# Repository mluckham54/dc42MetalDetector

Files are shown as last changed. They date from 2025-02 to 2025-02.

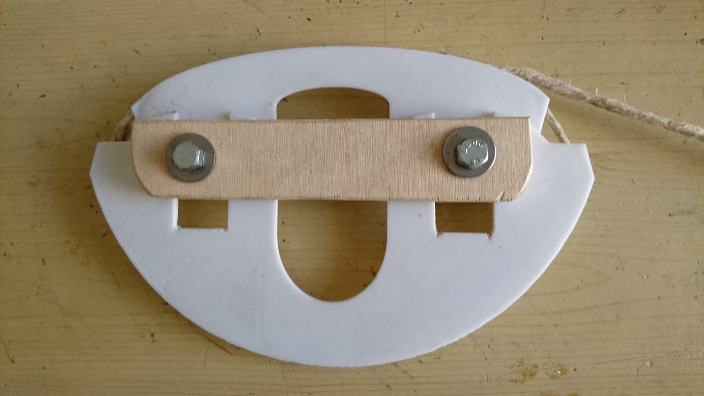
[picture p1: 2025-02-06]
MetalDetector/PrintableParts/DD Coil modifiable - 5966085 - 105percent/images/664fb390-7184-4ca7-937c-c71cdf0065e6.jpeg

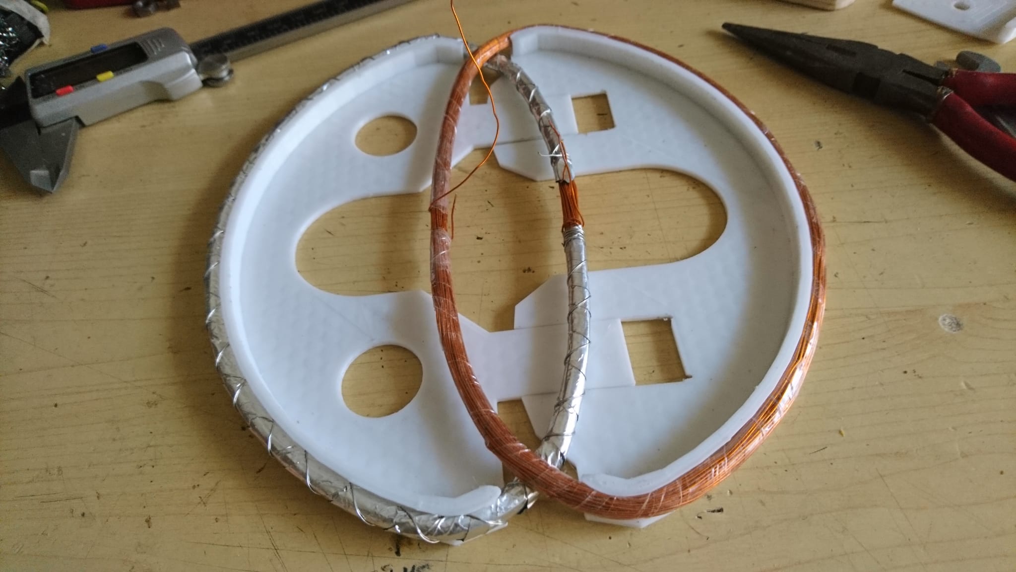
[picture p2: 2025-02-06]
MetalDetector/PrintableParts/DD Coil modifiable - 5966085 - 105percent/images/e20aad1c-73c8-4a4e-adeb-e24c117a30eb.jpeg

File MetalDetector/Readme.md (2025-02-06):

**Induction balance metal detector**

This project is an Induction Balance Metal Detector built around Arduino Uno and a 2-line LCD display module driven by I2C.  A piezo buzzer is used to drive an earphone for audio feedback.

The search coil comprises two D-shaped coils fastened on opposite side of a 230mm diameter plastic plate.  The coils are overlapped in the middle to null or minimize the amount of voltage and current induced into the receiver coil when no metal is present.  Position of the overlap is extremely critical, to tune the lowest voltage to an absolute minimum - at which point the Calibration routine can be run.

The form on which the coils are mounted was 3D printed from "DD Coil modifiable by Gabryxx on Thingiverse: https://www.thingiverse.com/thing:5966085".  The original coil was enlarged to 105% to fit the approx 16-cm coils which had already been wound.  In the end, the coil overlap is about 2.5 cm wide and 18 cm long.

The schematic for the detector was taken from Mirko Pavleski's project https://www.hackster.io/mircemk/diy-sensitive-arduino-ib-metal-detector-with-discrimination-b55e9d, modified to replace the LCD display with one I had on hand.  The dc24 project contains KiCad schematics, Mirko's project did not (only a JPG of the circuit).   The circuit was built up on a perfboard and does not seem to suffer from interference, however take care to use grounded shielded wire pairs running from the perfboard to the coils. Leave the shield grounds at the coil end unconnected.

After learning from the comments in Mirko's YouTube video https://www.youtube.com/watch?v=nkSPy0BPTFc&t=5s "DIY sensitive Arduino Induction Balance Metal Detector with Discrimination (15cm to 50 + cm)" came from David Crocker's github project https://github.com/dc42/arduino, it was decided to use his code rather than Mirko's.

The tuning capacitors across the coils should be adjusted such that the LC networks resonate exactly at the frequency generated by the Timer0 PWM output. An oscilloscope is critical to help understand the circuit and the code behaviour, and to tune the coil resonances and phase detection.  The tuning capacitors should be metallised foil types because stable, accurate values are needed. The other capacitors can be ceramic.

The code contains a lot of notes about the discovery process, tuning the coils, understanding how the code works, fixing some issues in the code, and extending it to my liking.

TODO:  wrap the coils in grounded aluminium foil (with a gap at one point so that it doesn't behave like a shorted turn) so that capacitance between the coils and the ground doesn't cause the system to go out of balance.

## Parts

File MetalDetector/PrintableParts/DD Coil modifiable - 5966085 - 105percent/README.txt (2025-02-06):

DD Coil modifiable by Gabryxx on Thingiverse: https://www.thingiverse.com/thing:5966085

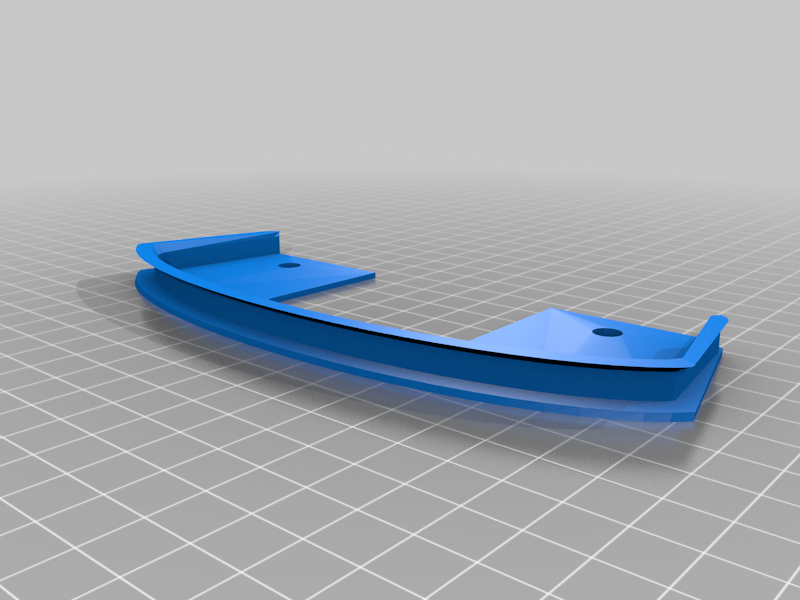
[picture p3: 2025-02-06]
MetalDetector/PrintableParts/DD Coil modifiable - 5966085 - 105percent/images/68960cd5-e284-4ff6-a99d-108c46c3dbc9.png

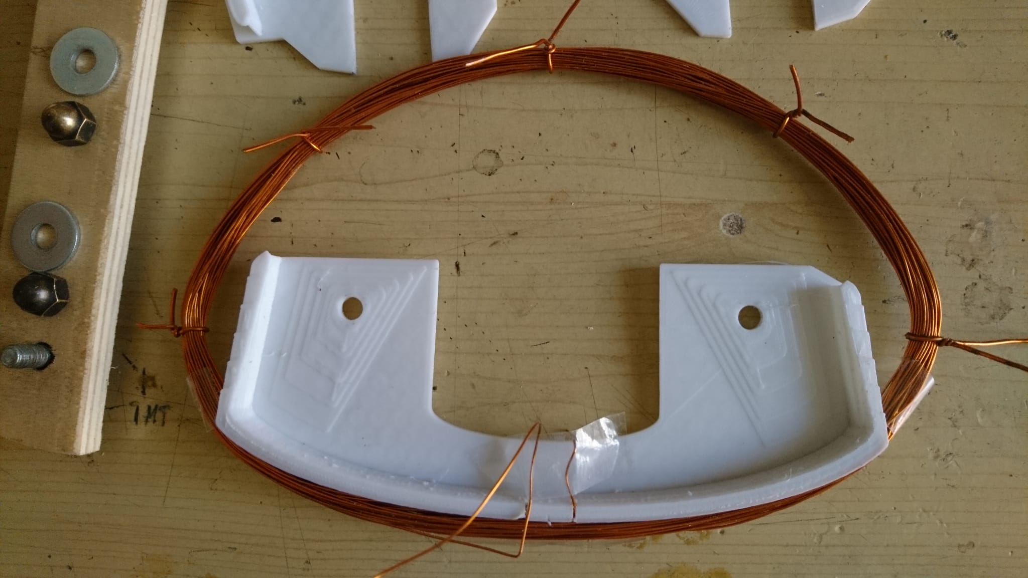
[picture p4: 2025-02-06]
MetalDetector/PrintableParts/DD Coil modifiable - 5966085 - 105percent/images/a11f1c0a-a7c3-48c4-930f-4ecd38f82f80.jpeg

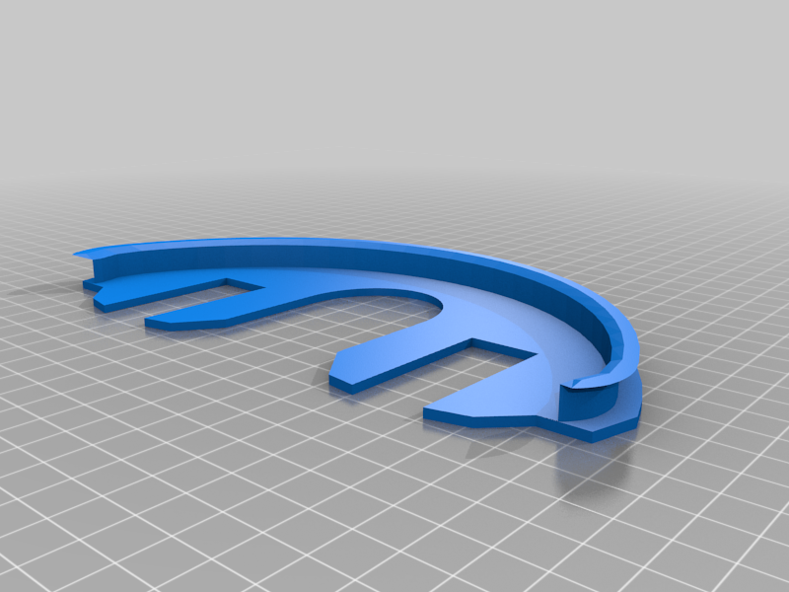
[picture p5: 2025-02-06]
MetalDetector/PrintableParts/DD Coil modifiable - 5966085 - 105percent/images/57a2fe57-1afa-487f-abc0-737dc57a6d6f.png

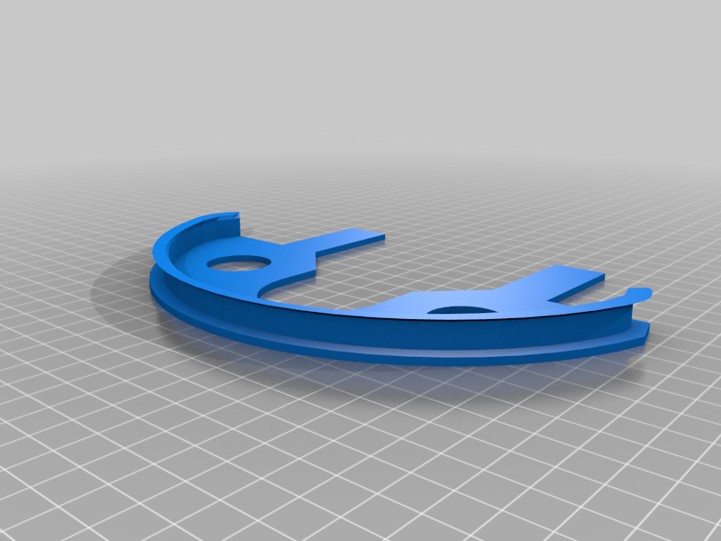
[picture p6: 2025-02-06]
MetalDetector/PrintableParts/DD Coil modifiable - 5966085 - 105percent/images/dc1d90d6-1bc5-4217-a439-5ab050d07a05.png

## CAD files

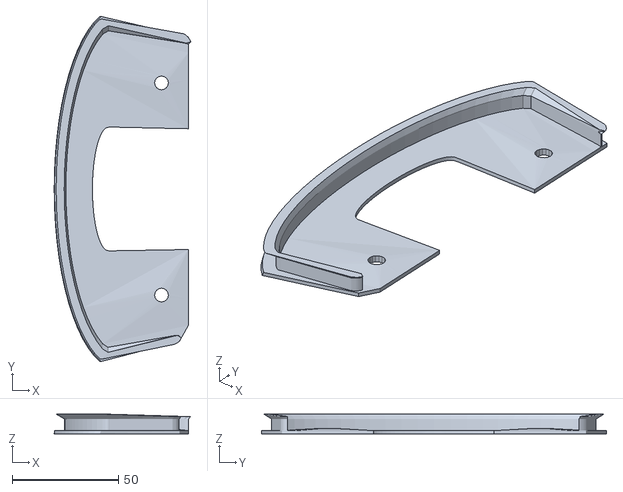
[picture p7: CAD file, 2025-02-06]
MetalDetector/PrintableParts/DD Coil modifiable - 5966085 - 105percent/files/C.stl
64.4 x 162.6 x 9.30

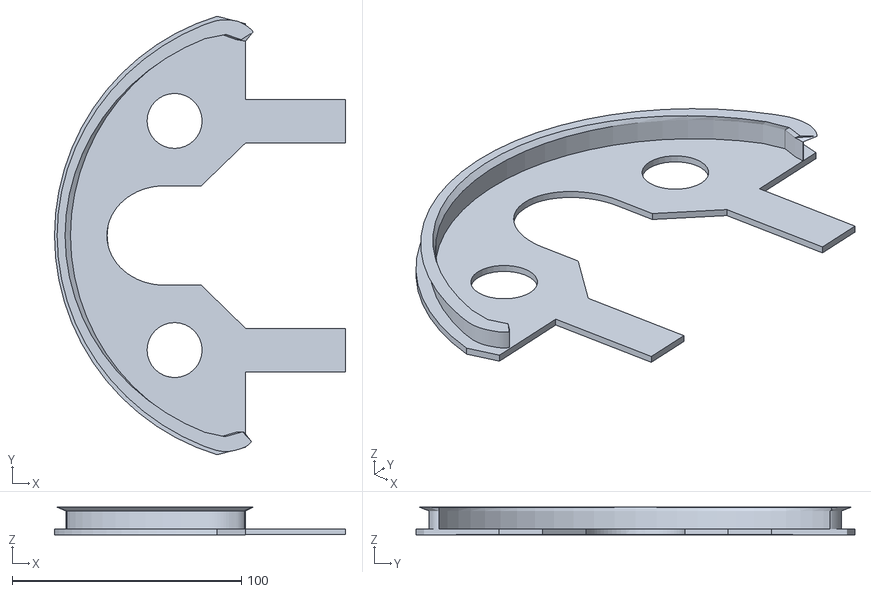
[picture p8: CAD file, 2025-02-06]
MetalDetector/PrintableParts/DD Coil modifiable - 5966085 - 105percent/files/A.stl
127.0 x 191.4 x 12.0

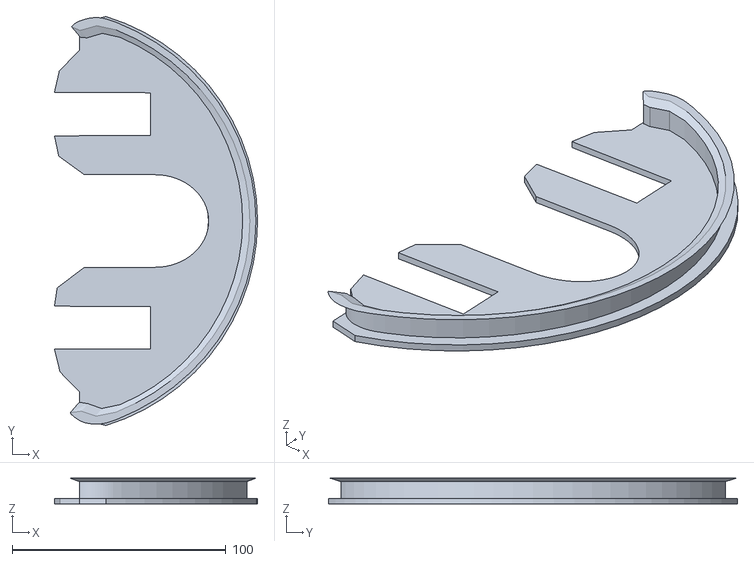
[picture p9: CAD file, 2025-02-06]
MetalDetector/PrintableParts/DD Coil modifiable - 5966085 - 105percent/files/B.stl
95.1 x 191.4 x 12.0

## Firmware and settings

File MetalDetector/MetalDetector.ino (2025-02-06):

// Induction balance metal detector (Mirko Pavleski)
// https://www.hackster.io/mircemk/diy-sensitive-arduino-ib-metal-detector-with-discrimination-b55e9d
// https://www.youtube.com/watch?v=BolEUTYOES0

// from original code by dc42 David Crocker (2013)
// https://github.com/dc42/arduino/blob/master/MetalDetector
//   (his version has support for battery power measurement and adjustable threshold)

// This is a VLF (very low frequency) Induction Balance detector technology and contains two identical coils : transmitter and receiver coil in
// a double-D arrangement.  As with all induction balance detectors, coil balance is very critical. The potentiometer is used to zero the small
// 90 degrees out-of-phase component of the signal (the in-phase component is nulled by adjusting the relative placement (overlap) of the coils
// in typical IB-detector style).
//
// Does the 90 degree out-of-phase component arise from the current in the coil lagging the voltage?  The current in the capacitor leads the voltage
// and is also 90 degrees out-of-phase.  https://eepower.com/technical-articles/understanding-resonance-in-parallel-rlc-circuits/#



// ********************************************************************************************************************
    
#define ENABLE_SOUND       (1)

// control what is printed to the COM port

#define PRINT_TICKS (0)
#define PRINT_ISR_VARS (0)
#define PRINT_ADC_MINMAX (0)
#define PRINT_VOLTS (1)
#define PRINT_FFT (0)
#define PRINT_AMPLITUDE (1)
#define PRINT_PHASE (1)
#define PRINT_AVERAGES (0)
#define PRINT_READINGS (0)
#define PRINT_MATERIAL (0)
#define PRINT_BARS (0)

// control what is dislayed on the LCD

#define DISPLAY_VOLTS (1)
#define DISPLAY_AMPLITUDE (1)
#define DISPLAY_PHASE (1)
#define DISPLAY_MATERIAL (0)



// TRANSMIT & RECEIVE COILS
//
// Two coils of same size and number of winding are required.  A variety of sizes could be considered, probably the larger and more windings the
// better, to have a stronger field pulse for the transmit and more sensitivity for the receive coil.  The voltage and maximum current that can be
// delivered to the coils must be considered also.
//
// The inductance and resonant frequency of a coil, and the parallel-resonance circuit formed by coil and capacitor, can be estimated.  Note that the
// current circulating between coil and capacitor is many times greater than the supply current.
//
// For the coil only: https://www.teslascientific.com/products/coil-resonant-frequency-calculator/
//     wire 0.45mm^2, 15cm dia, 0.5cm height, 44 turns - 1570 kHz, 630.500 µH, 14.400 pF
//     wire 0.45mm^2, 15.5 dia, 0.5cm height, 55 turns - 1333.757 kHz, 956.938 µH, 14.880 pF   (* BUILT)
//     wire 0.45mm^2, 16cm dia, 0.5cm height, 55 turns - 1290 kHz, 989.876 µH, 15.360 pF
//       10⁶ ÷ ((2 × 3.142 ) × √(989.876 µH × 15.360 pF))
//       ≈ 10⁶ ÷ (6.283 × √15204.495) ≈ 10⁶ ÷ (6.283 × 123.307)
//       Resonant Frequency ≈ 1000000 ÷ 774.758 = 1290.726 kilocycles/sec
//       Conductor Length = 3.141 × 0.160 Metres × 55 Turns = 27.646 Metres
//
// For the coil-capacitor L-C circuit: https://www.redcrab-software.com/en/Calculator/Electrics/RCL-Parallel-Resonance-Circuit
//     15.5 cm coil Inductor L  956.938 µH Capacitor C 470 nF Resistor R 1000 Ω Voltage U 5.5 V Decimal places 2   
//                  Resonance Frequency f0 7.5 kHz Total current I0 5.5 mA Currents IL, IC 121.89 mA
//                  Impedance XL/XC 45.12 Ω Q factor 22.16 Damping d 0.05 Bandwidth b 338.63 Hz Upper cut-off fH 7.67 kHz Lower cut-off fL 7.34 kHz
//
// A plastic plate was 3D printed from https://www.thingiverse.com/thing:5966085 (DD Coil Modifiable), enlarged to 105%.  The plate is in two parts,
// one for transmit and the other for receive coil.  The plates can slide together to form an overlap of the D-coils and fixed in place.  When
// installed on the plates, each coil (now D-shaped) is about 20.5 x 13 cm.
//
// Each of the coils was wound on 15.5 cm round form using 55 turns of 0.45mm^2 enameled copper wire.  The estimated diameter across the coil 0.5 cm.
// Wrap insulating tape around each coil to bundle the wires together, and form each into a D shape.  Add insulated leads from the coil (head) to run
// back to the electronics enclosure.
//
// The coils as-built were measured using a cheap ESD L/C meter.  The coil w/BL+WH wires was 987.8 uH, w/BLU+YEL wires 1029 uH - agreeing pretty closely
// to the calculated value of 956 uH.  Measurement was done after the coils were wrapped in tape, making it impossible to adjust the coil's inductance by
// adding or removing turns - instead, the capacitor values can be adjusted for equal resonance.
//
// OPTIONALLY screen one or both of the coils using aluminum foil bound with tinned copper wire (taking care to leave a small gap of 1-2 inches along one
//            part of the coil so that the screen doesn’t behave like a shorted turn).  Ground the shield, and tie-wrap the coils onto a plastic plate.
//            Some sources say that for audio frequencies, screening the coils makes no difference.  Some screen the transmit coil, some the receive coil,
//            some both. I did not screen the coils - experiments can come later.

// DRIVING THE TRANSMIT COIL AT ITS RESONANT FREQUENCY
//
// The Timer0 square wave drive the transmit coil, at around 8 kHz.  To determine the Timer0 square wave frequency:
//
//  - measure the coil inductance, or calculate after measuring the coil diameter, cross-sectional height, and number of turns.
//  - an interesting way to obtain the resonant frequency uses an oscilloscope across the coil or capitor-coil (in free space, not connecting to any
//    other circuit).  Tap a 1.5 volt battery across the circuit and watch the decaying sine wave on the scope.  The frequency of the sine wave
//    seems to be the resonant frequency.
//
//      Test 1 using the receiver coil (two 0.1uF ceramic capacitors gives around 500nF) around 22 kHz
//      Test 2                          one 0.1                                          around 16 kHz
//      Test 3                          two 0.1 in parallel, around 0.2 uF               around 11 kHz
//      Test 4                          three 0.1 in parallel, around 0.3 uF             around 8.9 kHz
//      Test 5                          one 0.47 uF                                      around 7.2 kHz
//      Test 6                          one 0.33 uF                                      around 8.6 kHz
//
//  - calculate the parallel-resonance frequency of the capacitor-coil combination.  At resonance, current moves alternately from the coil
//    to the capacitor and back, multiplying the input current that was required to charge the system.  The resonance current is higher than
//    the input current, and while in resonance the input current falls to zero.  Do these two times correspond to the peak and valley of the
//    50% duty cycle?  The resonance frequency of the LC circuit is much lower than the coil's inherent resonant frequency - and is the frequency
//    required for the square wave to drive the coil.
//
//    ONCE THE COIL FREQUENCY IS CLOSE, TIMER1_TOP (255), connect Timer0 square wave output to the coil as per the circuit.  Connect the scope
//    probe across the coil-capacitor combo, observe a sin wave at the same frequency (7-8 kHz) and measure the voltage amplitude.  Change
//    TIMER1_TOP to produce different frequencies around the calculated resonance frequency - choose the value whose output frequency maximizes
//    the voltage.
//
//  - adjust TIMER1_TOP to achieve that frequency while observing the sine wave amplitude on the scope.  Observe the square wave output by the
//    digital output is a sine wave on the scope.  Adjust TIMER1_TOP to produce a frequency that maximizes the amplitude - it should be close to the
//    estimated value from the calculators above.
//  - note that the amplitude will be dependent on the square wave peak-to-peak voltage, either 3.3V or 5V depending on the Arduino power
//    configuration.
//
// Adjusting the square wave drive frequency
//  - digital outputs on the Arduino Uno can handle 40 mA current max.  Connect a suitable resistor to one of the coil-capacitor leads to limit the
//    current below 40 mA, at the digital output voltage (3.3 or 5V).  The resonant capacitor-coil circuit will have a resistive value as well, it
//    can be calculated.  Connect the resistor and capacitor-coil to output D5.
//
//    RESULTS (unshielded, BLU&YEL, 55 turns, 15.5cm, 0.45mm2 wire, 1Kohm current-limit resistor to pin D5 which can safely supply 40mA, 0.33 uF ceramic capacitor (actual measured .305 uF)
//    225 = 8.842kHz 2.07Vp2p 722mVrms
//    233 = 8.539kHz 2.43Vp2p 854mVrms
//    238 = 8.361kHz 2.55Vp2p 906mVrms
//    240 = 8.292kHz 2.60Vp2p 922mVrms
//    242 = 8.223kHz 2.60Vp2p 923mVrms (*)
//                                       https://www.omnicalculator.com/physics/resonant-frequency-lc the inductance of the coil at 8.223kHz is 1,228.2 uH
//                                       https://www.teslascientific.com/products/coil-resonant-frequency-calculator/ wire 0.45mm^2, 15.5 dia, 0.5cm height, 55 turns - estimated resonance at 1333.757 kHz, 956.938 µH, 14.880 pF
//                                       https://www.redcrab-software.com/en/calculator/electrics/RCL-parallel-resonance-circuit the frequency is 8.22kHz, bandwidth 521Hz, Q 15.76, impedance 63.5ohms, total current 4mA, LC current 63mA
//    243 = 8.189kHz 2.58Vp2p 912mVrms
//    245 = 8.123kHz 2.55Vp2p 907mVrms
//    250 = 7.961kHz 2.36Vp2p 827mVrms
//
//    RESULTS (unshielded coil, BLK&WH, 55 turns, 15.5cm, 0.45mm2 wire, 1Kohm current-limit resistor to pin D4 which can safely supply 40mA, 0.33 uF ceramic capacitor (actual measured .308 uF)
//    240 = 8.291kHz 2.45Vp2p 868mVrms
//    242 = 8.223kHz 2.53Vp2p 906mVrmw
//    243 = 8.189kHz 2.57Vp2p 920mVrms
//    245 = 8.123kHz 2.60Vp2p 935mVrms
//    249 = 7.993kHz 2.65Vp2p 945mVrms (*) THIS COIL HAS THE HIGHER OUTPUT BUT AT A LOWER FREQUENCY THAN THE OTHER COIL
//                                       https://www.omnicalculator.com/physics/resonant-frequency-lc the inductance of the coil at 7.993kHz is 1,287.3 uH
//                                       https://www.teslascientific.com/products/coil-resonant-frequency-calculator/ wire 0.45mm^2, 15.5 dia, 0.5cm height, 55 turns - estimated resonance at 1333.757 kHz, 956.938 µH, 14.880 pF
//                                       https://www.redcrab-software.com/en/calculator/electrics/RCL-parallel-resonance-circuit the frequency is 7.99kHz, bandwidth 517Hz, Q 15.47, impedance 64.6ohms, total current 4mA, LC current 62mA
//   voltage across the 1K resistor 5.7Vp2p 2.85Vrms (current 2.85/1000 = 2.8mA).  voltage across coil at 63.5ohm impedance (current .923V/63.5 = 0.0145 = 14 mA)
//   voltage D5 to GND 3.28Vrms, resistance 1000 + 63.5, current 3.28/1063.5 = 0.0031 = 3mA
//   
//    250 = 7.961kHz 2.65Vp2p 944mVrms
//    251 = 7.929kHz 2.63Vp2p 937mVrms
//    252 = 7.898kHz 2.60Vp2p 929mVrms

// TWEAKS
// ***   adding capacitance (10nF across the coil) lowers the RMS volts.  Use this to 'tune' the two coils to peak equally at the same frequency
// ***   change to 5V from 3.3V
// ***   adjust current-limit resistor.  If halved, voltage across the coil will go up - it's worth exploring how much current because the coil output should be improved
//                          (2) 1K resistors in parallel)  ... 1.6 Vrms across the coil vs 850mV-ish at 1K resistor
//                          recommended 100-470 ohms for current limiting, abs max 40mA but continuous 20mA limit recommended.  Total output pins current 200mA max.
//                          digital pins consume the most current when driven low


// HOW THE SQUARE WAVE IS GENERATED
//
//   The CPU clock is 16MHz and the ADC clock at 1MHz. ADC resolution is reduced to 8 bits at this speed.
//
//   Timer 1 is used to divide the system clock by about 256 to produce a 62.5kHz square wave (see the TIMER1_TOP which determines the frequency).
//
//   This is used to drive timer 0 and also to trigger ADC conversions.
//
//   Timer 0 is used to divide the output of Timer 1 by 8, giving (about) 7.8125kHz signal for driving the transmit coil.  This frequency should be the RLC
//   resonance frequency.
//
//   This allows time for 16 ADC clock cycles for each ADC conversion (it actually takes 13.5 cycles), and we take 8 samples per cycle of the coil drive voltage.
//   The ADC implements four phase-sensitive detectors at 45 degree intervals. Using 4 instead of just 2 allows us to cancel the third harmonic of the
//   coil frequency.
//      WHY MENTION THE 3RD HARMONIC?  7.8125, 15.625, 23.4375, 31.25kHz
//      https://powerquality.blog/2023/09/08/effect-of-harmonics-on-power-transformers-a-practical-demonstration-and-analysis/
//         2nd harmonic lowers the second half of each half-phase
//         3rd harmonic lowers the peak of each half-phase
//
//   Timer 2 is used to generate a tone for the earpiece or headset.
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
void loop()
{
  digitalWrite(blinkPin, LOW);   // OFF

  // a new sample in averages[] will be available approximately once/second .. 8192 ticks
  // NOTE one sampleReady interval is already 1 second or about 8000 samples!
 
  while (!sampleReady) {}
  
  uint32_t oldTicks = ticks;
  uint32_t sampleReadyLatency = 0;
  
  if (digitalRead(encoderButtonPin) == LOW)
  {
    // Calibrate button pressed. Save the average coil voltage to subtract from future results.
    // This lets us use the detector if the coil is slightly off-balance.
    // Calibration can be repeated as often as needed.
    
    lcd.setCursor(0,0);
    lcd.print("Calibrating...  ");

    Serial.print("Calibrating");

    calibratedVolts = 0;
    calibratedPhase = 0;
    
    const int CalibrationCycles = 100;
    for( int cycles=0; cycles<CalibrationCycles; cycles++)
    {
      volts = (readingsMax-readingsMin) * voltsPerAdcCount;
      calibratedVolts = (calibratedVolts + volts)/2;
      
      while (!sampleReady) {}
      
      Serial.print('.');
    }

    calibrated = true;

    // erase "Calibrating...  "
    lcd.setCursor(0,0);
    lcd.print("                ");

    sampleReady = false;
    sampleReadyLatency = ticks - sampleReadyTicks;
    sampleReadyTicks = 0;

    Serial.print("done: ");

    Serial.println(calibratedVolts);

    return;
  }


  
  const double f = 8000.0;    // 200.0;

  // I think the averages index (0-3) represents the Timer0 output waveform phase since the ctr value in the ISR
  // determines which bin is filled with the ADC value at that moment.  The value itself represents the waveform
  // on the receiver coil.  As only one waveform (the received) is provided, phase shift is computed based on which
  // of the averages[] elements *WITH RESPECT TO THE TX WAVEFORM TIMES* is higher or lower than expected.

  // averages[] are provided to loop() at about a 1Hz rate (8192 ticks)

  // Massage the results to eliminate sensitivity to the 3rd harmonic (Timer0 freq x 3), and divide by 200
  // Why 200?  Why is the 3rd harmonic a concern?  How does this math desensitize?
  //     - 2nd harmonic tends to lower the sin peak at 90 and 270 deg
  //     - 3rd harmonic tends to lower the right half the peak between 90-180

  // averages[0..3] contains the net difference at a certain phase angle of the first half of a TX (transmitted) clock cycle, minus the same phase angle of the second half of the clock cycle.
  //   The RX (received) signal will track the TX signal at a lesser amplitude and with a phase shift.
  
  // Compute the amplitude and the amount of phase shift - using FOURIER ANALYSIS.
  // https://stats.stackexchange.com/questions/541277/how-can-i-get-the-phase-difference-between-two-frequencies
  // https://forum.arduino.cc/t/program-to-find-zero-crossing-of-a-sinusoidal-wave/443323/7
  // If you know the frequency, sample them - not sure how many samples you need - then do a simple fourier analysis. Use micros() to control when you take the samples.
  // For instance, if your sine waves are 50Hz, that's 20ms. Take samples at the 1ms mark gives you 20 samples per cycle. Pre compute sine and cosine of 2pi/20 * n.
  //   Take your samples. multiply them by the sines and cosines and average each. atan2 of those will give you the phase.
  //
  // https://www.linkedin.com/pulse/how-fft-algorithm-works-part-2-divide-and-conquer-mark-newman/
  
  // Complex number
  double f0real = (averages[0] + halfRoot2 * (averages[1] - averages[3]))/f;           // the Real part at 0deg
  double f0cmpl = (averages[1] + halfRoot2 * (averages[0] + averages[2]))/f;           // the Complex part at 45deg
  
  double f1real = (averages[2] + halfRoot2 * (averages[1] + averages[3]))/f;           // the Real part at 90deg
  double f1cmpl = (averages[3] + halfRoot2 * (averages[2] - averages[0]))/f;           // the Complex part at 135deg

  // compute magnitude (amplitudes) 
  double amp1 = sqrt((f0real * f0real) + (f1real * f1real));
  double amp2 = sqrt((f0cmpl * f0cmpl) + (f1cmpl * f1cmpl));
  double ampAverage = (amp1 + amp2)/2.0;

  // The ADC sample/hold takes place 2 clocks after the timer overflow
  //  ?? two Timer1 clocks ??

  // compute the phase angle - slopes to radians to degrees?
  double phase1 = atan2(f0real, f1real) * radiansToDegrees + 45.0;
  double phase2 = atan2(f0cmpl, f1cmpl) * radiansToDegrees;

  if (phase1 > phase2)
  {
    // swap the phase values
    double temp = phase1;
    phase1 = phase2;
    phase2 = temp;
  }

  double phaseAverage = ((phase1 + phase2)/2.0) - phaseAdjust;                  // (45.0 * 32.0) / (float)(TIMER1_TOP + 1);

  // change the sign of the phase, since the ISR only collected the second half of the PWM cycle whose amplitude is generally opposite of the first half
  // when compared to phase calculated by an oscilloscope, the values agree closely (although not exactly) prior to adjusting for phaseCalibration
  // on the Rigol 1052E, with Ch1 the PWM pulse and Ch2 the output from the OPAMP
  //   if the positive peak of the wave is nearest to the rising edge of the PWM output the phase is negative (around -90 degrees if right on the edge)
  //   if the positive peak is nearest to the falling edge of the output the phase is positive (around 90 degrees if right on the edge)
  //   if the positive peak is in the middle of the PWM positive pulse, the phase is zero
  // metal passing over the non-overlapping parts of the coils produces a negative phase shift, while in the neutral middle will show positive
  // best sensitivity and range is in the middle when the coil is adjusted for minimum voltage (60 mA or less)
  
  phaseAverage = -phaseAverage;

  phaseStable = abs(previousPhase - phaseAverage) <= 5.0;      // phase fluctuates wildly especially when the signal voltage is very low
  previousPhase = phaseAverage;

  // phase part of calibration
  if(calibrated && calibratedPhase == 0)
  {
    // displayed phase will become the phase relative to calibration
    // caution. near minimum coil voltage phase fluctuates wildly
    calibratedPhase = phaseAverage;
  }
  
  double displayPhase = phaseAverage - calibratedPhase;

  volts = (readingsMax-readingsMin) * voltsPerAdcCount;
  voltsAmplitude = (volts - calibratedVolts);

  if (readingsMisses > 0)
  {
    digitalWrite(blinkPin, HIGH);  // turn on the overflow LED ('L' on the Arduino board)
  }
  
  // ***** NO CALCULATIONS BELOW HERE - ONLY OUTPUTS *****


#if PRINT_TICKS    
  Serial.print(ticks);    // current ISR clock tick - theoretically 8192 but actually 8000-8039 per sample
  Serial.write(' ');
#endif

#if PRINT_ISR_VARS
  Serial.print(sampleReadyLatency);
  Serial.write(' ');
  Serial.print(readingsMisses);
  Serial.print('/');
  Serial.print(samplesToAccumulate);
  Serial.write(' ');
#endif

#if PRINT_ADC_MINMAX
  Serial.print(readingsMin);
  Serial.write(' ');
  Serial.print(readingsMax);
  Serial.write(' ');
#endif

#if PRINT_VOLTS
  Serial.print(volts, 3);
  Serial.write(' ');
#endif

#if PRINT_FFT
  // fourier series
  if (f0real >= 0.0) Serial.write(' ');  // prints a space where the minus sign would be
  Serial.print(f0real, 2);
  Serial.write(' ');
  
  if (f0cmpl >= 0.0) Serial.write(' ');
  Serial.print(f0cmpl, 2);
  Serial.write(' ');
  
  if (f1real >= 0.0) Serial.write(' ');
  Serial.print(f1real, 2);
  Serial.write(' ');
  
  if (f1cmpl >= 0.0) Serial.write(' ');
  Serial.print(f1cmpl, 2);
  Serial.write(' ');

  // fourier magnitudes
  Serial.print(amp1, 2);
  Serial.write(' ');
  
  Serial.print(amp2, 2);
  Serial.write(' ');

  if (phase1 >= 0.0) Serial.write(' ');
  Serial.print(phase1, 2);
  Serial.write(' ');
  
  if (phase2 >= 0.0) Serial.write(' ');
  Serial.print(phase2, 2);
  Serial.print("    ");
#endif

#if PRINT_AMPLITUDE
  // waveform amplitude after integration
  if (ampAverage >= 0.0) Serial.write(' ');
  Serial.print(ampAverage, 2);

  // volts amplitude
  if (voltsAmplitude >= 0.0) Serial.write(' ');
  Serial.print(voltsAmplitude, 2);
  Serial.write(' ');
#endif

#if PRINT_PHASE
  if (phaseAverage >= 0.0) Serial.write(' ');
  Serial.print(phaseAverage, 0);
  Serial.write(' ');

  Serial.print(displayPhase, 0);
  Serial.write(' ');

  if (!phaseStable)
  {
    Serial.print("unstable");
    Serial.write(' ');
  }
#endif

#if PRINT_AVERAGES
  Serial.println();  
  for (int i=0;i<4; i++)
  {
    Serial.println(averages[i]);   // one value per line for the Serial Plotter
  }
  Serial.write(' ');
#endif

#if PRINT_READINGS
  Serial.println();  
  for (int i=0;i<8; i++)
  {
    Serial.println(readings[i]);
  }
  Serial.write(' ');
#endif

  ticks = 0;
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

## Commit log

2025-02-06 Replaced INO with working code, added photos, schematics, updated the Readme
2025-02-06 add photos, schematics, 3D print files
    [A.stl, B.stl, C.stl]
